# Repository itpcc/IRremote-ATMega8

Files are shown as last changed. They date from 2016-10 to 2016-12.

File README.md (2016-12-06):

# IRremote-ATMega8

This project is for creating a device to control electronic device with infrared controlled by Smartphone or anything which can connected by Wi-Fi via ESP8266 (However, we communicate with ESP8266 via Serial due to subject restriction policy).

This project is created by:

- [Mr. Pongpon Kampan](https://github.com/owlaaz)
- [Mr. Rachasak Ragkamnerd](https://github.com/itpcc)

This project is a project of CPE363 Embedded device from [CPE KMUTT](https://cpe.kmutt.ac.th).

## Schematic

[Eagle file](Schematic/schematic.sch)

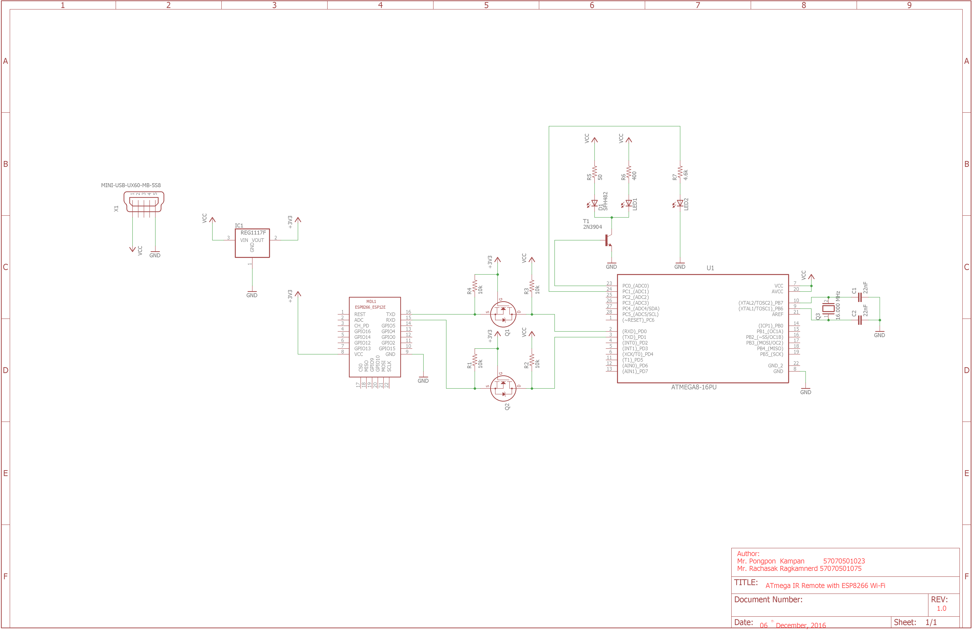
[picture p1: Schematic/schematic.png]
Eagle file


## Read more

- [Custom protocol (applied from NMEA protocol) used in this project (in Thai)](ir_protocol.md)
- [Example Android application used for project demo](https://github.com/owlaaz/IRRemote-Mobile-To-ESP8266)
- [Project Report](Project Report.pdf)

## Applied repository
- [Arduino IR Remote](https://github.com/z3t0/Arduino-IRremote)
- [Daikin IR Remote](https://github.com/mharizanov/Daikin-AC-remote-control-over-the-Internet)

## Resource 

- [IR Database](http://irdb.tk/api)
- [Using AVR UART](http://www.appelsiini.net/2011/simple-usart-with-avr-libc)
- [Logic level converter](https://learn.sparkfun.com/tutorials/bi-directional-logic-level-converter-hookup-guide)
- [Schematic for LIRC](http://alexba.in/blog/2013/03/09/raspberrypi-ir-schematic-for-lirc/)
- [AVR fus bit calculator](https://elektronik-kompendium.de/public/arnerossius/programme/web/avrfuse/m8fuse.html)
- [USBasp](http://eecs.oregonstate.edu/education/docs/ece375/USBASP-UG.pdf#page=8)

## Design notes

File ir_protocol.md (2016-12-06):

Protocol

Reference: [NMEA Protocol](https://en.wikipedia.org/wiki/NMEA_0183)

# รับ IP ที่จะให้ติดต่อ (UDP)

```
$IRCIP,192.168.1.112*47
        |----------|
          Phone IP
```

# ขอคำสั่ง (ESP-TCP)
```
$IRREQ,00000*41
         |
         --- IR Sent command ID (00000 if no command sent) คำสั่งล่าสุดที่ทำไปแล้ว
```

# ส่งคำสั่ง (จากเครื่องควบคุม) (Mobile-TCP)
```
$IRCMD,1,00FAF,RC5,48260482,12*73
       |   |    |      |     |
       |   |    |      |     --- nbits (ถ้ามีระบุใน IR Command) หรือ address กรณี panasonic
       |   |    |      --- Command HEX code 
       |   |    --- protocol (3 char)
       |   --- Command unique ID (5 alphanumeric)
       --- Remaining command count (1 ยังเหลือ 0 หมดแล้ว)
$IRCMD,0,00001,NEC,A1DE21DE,32*46
```

## Protocol
- RC5
- RC6
- PAN (Panasonic)
- NEC
- SAM (Samsung)

# ไม่มีข้อมูลให้ทำ :v

```
$IREMP*44
```

# Invalid received command
```
$IRIVD*40
```

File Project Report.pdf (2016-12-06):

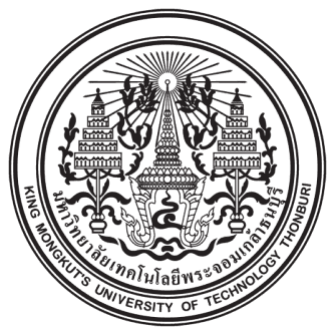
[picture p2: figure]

# Final Project Universal IR Remote

นายราชศักดิ์ รักษ์ก าเนิด | 57070501075
นายปองพล | ค าปัน | 57070501023

# วิชา Embedded Systems Design CPE 363 ภาควิชาวิศวกรรมคอมพิวเตอร์

# มหาวิทยาลัยเทคโนโลยีพระจอมเกล้าธนบุรี

ก

ชื่อโครงงาน | : | Universal IR Remote
ชื่อผู้จัดท าโครงงาน | : | นายปองพล | ค าปัน
นายราชศักดิ์ รักษ์ก าเนิด
อาจารย์ที่ปรึกษา | : | นายไกรกร | เศรษฐไกรกุล
| | นายธกรตั้งมั่นคง
คณะวิศวกรรมศาสตร์
ภาควิชาวิศวกรรมคอมพิวเตอร์
มหาวิทยาลัยมหาวิทยาลัยเทคโนโลยีพระจอมเกล้าธนบุรีสารบัญ
| | | บทคัดย่อ

ปัจจุบันทุกๆบ้านล้วนแต่มีเครื่องใช้ไฟฟ้า ที่คอยอ านวยความสะดวกสบายให้แก่ผู้ใช้งาน โดยส่วนใหญ่ล้วนแล้วแต่ใช้รีโมท ควบคุมการท างาน โดยการที่จะสั่งการท างานจากรีโมทนั้นจะท าการส่งชุดข้อมูลที่ประกอบไปด้วยค าสั่งฐานสิบหก (hex commmand)และรูปแบบรหัส ผ่านสัญญาณอินฟราเรด รีโมททุกๆเครื่องนั้นจะมีรูปแบบสัญญาณอินฟราเรดที่ส่งออกนั้น ต่างกัน ท าให้เกิดค าสั่งควบคุมที่ต่างกัน รวมไปถึงรูปแบบของการถอดรหัสที่แต่ละผู้ผลิตเครื่องใช้ไฟฟ้ามีรูปแบบเฉพาะที่ไม่ เหมือนกัน หากเรารู้ถึงค าสั่งฐานสิบหกและรูปแบบรหัสอุปกรณ์นั้นๆ เราสามารถเลียนแบบสร้างสัญญาณอินฟราเรดเพื่อสั่งให้ อุปกรณ์เหล่านั้นท างานได้Universal IR Remote จะเป็นอุปกรณ์ที่ท าการรวบรวมค าสั่งฐานสิบหกและรูปแบบของการถอดรหัส แต่ละอุปกรณ์ไว้และท าการสร้างสัญญาณอินฟราเรดของชุดข้อมูลเหล่านั้นเพื่อควบคุมอุปกรณ์ท าให้มีสะดวกยิ่งขึ้น อีกทั้งยัง เพื่อให้ผู้ศึกษาเข้าใจถึงการท างานของส่วนต่างๆ ในวงจรทั้งการท างานของ ESP8266,ATmega8 และ LED เพื่อประโยชน์ต่อการ น าไปศึกษาต่อไปในอนาคต

ค าส าคัญ : ค าสั่งฐานสิบหก, รูปแบบของรหัส, สัญญาณอินฟราเรด,ควบคุม

ข

กิตติกรรมประกาศ
โครงงาน Universal IR Remote ได้รับความช่วยเหลืออย่างสูงจากอาจารย์ไกรกร เศรษฐไกรกุลและอาจารย์ธกร ตั้ง มั่นคงอาจารย์ที่ปรึกษาโครงงาน ที่กรุณาสละเวลาช่วยให้ค าปรึกษาแนะน า และตรวจสอบ แก้ไข ข้อพกพร่องทุกขั้นตอนของการ จัดท าโครงงาน เพื่อพัฒนาปรับปรุงโครงงานให้มีประสิทธิภาพมากขึ้น ตลอดจนคอยติดตามเอาใจใส่ความคืบหน้าของโครงงานนี้อยู่ เสมอ จึงท าให้โครงงานนี้ส าเร็จลุล่วงไปได้ด้วยดี คณะผู้จัดท าจึงขอกราบขอบพระคุณเป็นอย่างสูงมา ณ ที่นี้
ขอขอบคุณเจ้าหน้าที่ Hardware House ที่สนับสนุนให้ยืมอุปกรณ์ จนโครงงานนี้สามารถส าเร็จลุล่วงไปได้ด้วยดี ขอขอบคุณอาจารย์ เพื่อนในชั้นเรียน และคณะผู้จัดท าโครงงานที่คอยเป็นก าลังใจให้ให้ความช่วยเหลือ ให้ค าปรึกษา

คณะผู้จัดท าโครงงาน

ค

สารบัญ

เรื่อง | หน้า
บทคัดย่อ | ก
กิตติกรรมประกาศ | ข
สารบัญ | ค-ง
บทที่ 1 บทน า | 1
1.1 ความเป็นมาและความส าคัญของโครงงาน | 1
1.2 วัตถุประสงศ์ของโครงงาน | 1
1.3 ขอบเขตการศึกษา | 1
1.4 แผนการด าเนินงาน | 1
1.5 ผลที่คาดว่าจะได้รับ | 1
บทที่ 2 เอกสารที่เกี่ยวข้อง
2.1 อินฟราเรด | 2
2.2 AVR Microcontroller | 2
2.3 รีโมตคอนโทรล | 3
2.4 Embedded System | 3
บทที่3 การออกแบบวงจร | 4-6
3.1 อุปกรณ์ที่ใช้ | 4
3.2 Diagram การท างาน Universal IR Remote | 4
3.3 Flow Chart แสดงการท างานของ Universal IR Remote | 4-5
3.4 ค าสั่งติดต่อการท างานระหว่าง โทรศัพท์มือถือ และ ESP8266 (Request & Response) | 6
บทที่ 4 ผลการทดลอง | 7-9
4.1 Schematic Universal IR Remote | 7
4.2 ล าดับการท างาน | 7-9
บทที่ 5 อภิปรายและสรุปผลการทดลอง | 10
5.1 อภิปรายผลการทดลอง | 10
5.2 สรุปผลการทดลอง | 10
5.3 ข้อเสนอแนะ | 10

ง

บรรณานุกรม | 10
ภาคผนวก | 11

บทที่ 1 บทน า

### 1.1 ที่มาและความส าคัญ

เนื่องจากในปัจจุบันการควบคุมเครื่องใช้ไฟฟ้า อุปกรณ์ภายในบ้านถูกควบคุมผ่านรีโมทคอนโทลที่มีสัญญาณอินฟราเรด เป็นตัวส่งรหัสค าสั่ง เมื่อเรามีเครื่องใช้ไฟฟ้า อุปกรณ์มากขึ้น รีโมทจะต้องมีมากขึ้นตาม คณะผู้จัดท าจึงมีแนวคิดที่ว่ารีโมทหนึ่งอัน สามารถควมคุมอุปกรณ์ได้ทุกอย่าง และรีโมทนั้นไม่จ าเป็นต้องรีโมทเสมอไป เพื่อให้สะดวกต่อการใช้งาน คณะผู้จัดท าจึงได้เลือกใช้ อุปกรณ์โทรศัพท์มือถือที่ทุกคนมีติดตัว ท าเป็นรีโมทควบคุมแทน จึงเกิดเป็น universal IR remote โดยได้น าความรู้ในวิชา CPE 363 Embedded System Design มาเป็นพื้นฐานในการท าโครงงาน

### 1.2 วัตถุประสงค์ของโครงงาน

1.เพื่อศึกษาและสร้าง IR Remote ที่สามารถควบคุมอุปกรณ์ไฟฟ้าได้หลายชนิด

### 1.3 ขอบเขตการศึกษา

สร้าง Remote ควบคุมบนโทรศัพท์มือถือ ที่ส่งชุดค าสั่งผ่าน TCP/UDP ไปยัง ESP8266 ที่เชื่อมต่อในเครือข่ายเดียวกัน และESP8266 ส่งค าสั่งการท างานไปที่ ATmega8 เพื่อให้ ir led ส่งสัญญาณอินฟราเรดตามค าสั่งที่ได้รับให้กับอุปกรณ์ไฟฟ้า

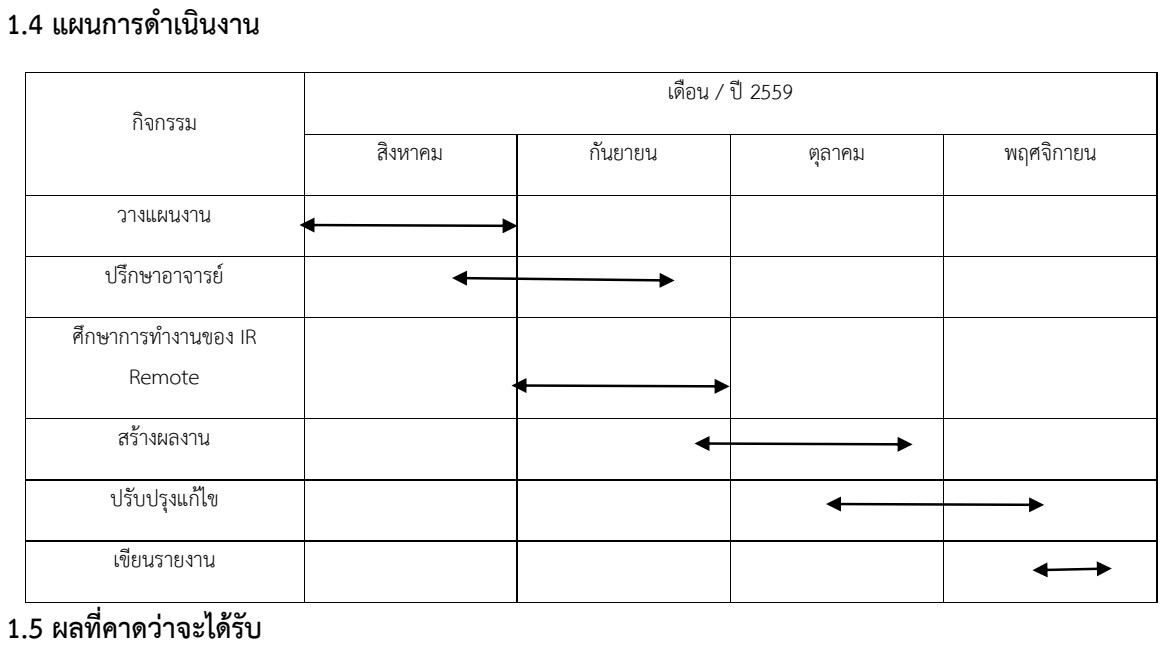
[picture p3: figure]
1.4 แผนการด าเนินงาน; กิจกรรม; สิงหาคม; กันยายน; ตุลาคม; พฤศจิกายน; วางแผนงาน; ปรึกษาอาจารย์; ศึกษาการท างานของ IR Remote; สร้างผลงาน; ปรับปรุงแก้ไข; เขียนรายงาน 1.5 ผลที่คาดว่าจะได้รับ

1. สร้าง universal IR remote ที่ใช้งานได้จริง
2. ความรู้จากการใช้งาน ESP8266,ATmega8,TCP/UDP protocol น าไปต่อยอดกับงานในอนาคต

บทที่ 2 เอกสารและโครงงานที่เกี่ยวข้อง

### 2.1 อินฟราเรด

รังสีอินฟราเรด (Infrared (IR)) มีชื่อเรียกอีกชื่อว่า รังสีใต้แดง หรือรังสีความร้อน เป็นคลื่นแม่เหล็กไฟฟ้าที่มีความยาว คลื่นอยู่ระหว่างคลื่นวิทยุและแสงมีความถี่ในช่วง 1011 – 1014 เฮิร์ตซ์ มีความถี่ในช่วงเดียวกับไมโครเวฟ มีความยาวคลื่นอยู่ ระหว่างแสงสีแดงกับคลื่นวิทยุสสารทุกชนิดที่มีอุณหภูมิอยู่ระหว่าง -200 องศาเซลเซียสถึง 4,000 องศาเซลเซียส จะปล่อยรังสี อินฟราเรดออกมา คุณสมบัติเฉพาะตัวของรังสีอินฟราเรด เช่น ไม่เบี่ยงเบนในสนามแม่เหล็กไฟฟ้า ที่แตกต่างกันก็คือ คุณสมบัติที่ ขึ้นอยู่กับความถี่ คือยิ่งความถี่สูงมากขึ้น พลังงานก็สูงขึ้นด้วย
ในการใช้ประโยชน์ ใช้ในการควบคุมเครื่องใช้ระบบไกล (remote control) สร้างกล้องอินฟราเรดที่สามารถมองเห็นวัตถุ ในความมืดได้ เช่น อเมริกาสามารถใช้กล้องอินฟราเรดมองเห็นเวียตกงได้ตั้งแต่สมัยสงครามเวียดนาม และสัตว์หลายชนิดมีนัยน์ตา รับรู้รังสีชนิดนี้ได้ ท าให้มองเห็นหรือล่าเหยื่อได้ในเวลากลางคืน
การประยุกต์ใช้อินฟราเรดในชีวิตประจ าวัน
กล้องถ่ายรูปใช้กลางคืน และกล้องส่องทางไกลที่ใช้ในเวลากลางคืน แสดงภาพความร้อน เพิ่มความปลอดภัยเวลาขับรถ ในเวลากลางคืน
รีโมทคอนโทรลในเครื่องใช้ไฟฟ้าก็เป็นอินฟราเรดอีกชนิดหนึ่ง
การไล่ล่าทางทหาร มิดไซ ที่ใช้ไล่ล่าเครื่องบินก็เป็นอินฟราเรดอีกชนิดหนึ่ง
เครื่องก าเนิดความร้อนทั่วไป เช่นเตาแก๊สอินฟราเรดในครัวเรือน เครื่องก าเนิดความร้อนในห้องซาวด์น่า
แผ่นกายภาพบ าบัด มีเป็นประคบร้อนอินฟราเรด ปัจจุบันเป็นวิธีการ กายภาพบ าบัดที่ปลอดภัยชนิดหนึ่ง
เช่น ความร้อนอุณหภูมิต่ ามาจากอินฟราเรด สามารถซึมเข้าลึกถึงผิวหนัง 1-1.5นิ้ว ลดอาการปวดหัวเข่า หรือท าให้แผล เรื้อรัง โลหิตหมุนเวียนดีขึ้นจึงท าให้แผลหายเร็ว
ข้อดี
สามารถเคลื่อนย้ายอุปกรณ์ได้ง่าย
ไม่ต้องติดตั้งสัญญาณ
ข้อเสีย
ต้องไม่มีสิ่งใดมากีดขวางเส้นสายตาของทั้งเครื่องรับและเครื่องส่ง
ระยะทางในการส่งข้อมูลสั้น

### 2.2 AVR Microcontroller

AVR Microcontroller คือ IC Microcontroller ของบริษัท Atmel ที่มีสถาปัตยกรรมภายในเป็นแบบ RISC (reduced instruction set computer) โดยใช้สัญญาณนาฬิกาเพียง 1 ลูกในการปฏิบัติงานใน 1 ค าสั่ง ภายใน AVRโดยจะ ประกอบด้วยหน่วยความจ าโปรแกรมภายในที่เป็นแบบแฟลช์โปรแกรมข้อมูลได้แบบ In-System programmable ซึ่งการท างาน ของ AVR เบอร์ต่างๆ จะมีความสามารถในการที่แตกต่างกัน เพื่อรองรับรูปแบบการท างานของวงจรที่หลายหลาก

### 2.3 รีโมตคอนโทรล

รีโมตคอนโทรล (remote control) คือเครื่องมืออิเล็กทรอนิกส์ชนิดหนึ่ง ใช้ส าหรับควบคุมการด าเนินการของ สิ่งประดิษฐ์หรือเครื่องจักรต่างๆ โดยเฉพาะเครื่องใช้ไฟฟ้าภายในบ้านเช่น โทรทัศน์ เครื่องเสียง เครื่องเล่นดีวีดี จากระยะไกล โดย ไม่ใช้สายไฟเป็นตัวส่งสัญญาณ แต่ใช้อินฟราเรดแทน (หรือใช้สัญญาณวิทยุแต่พบได้น้อย) ใช้พลังงานจากแบตเตอรี่ขนาดเล็กไม่กี่ ก้อนเท่านั้น มีขนาดเหมาะมือ และมีปุ่มฟังก์ชันต่างๆ อยู่ครบครัน
รีโมตคอนโทรล เป็นการเรียกย่อมาจาก รีโมตคอนโทรลเลอร์ (remote controller) อีกต่อหนึ่ง และสามารถเรียกย่อลง ได้อีกเหลือเพียง รีโมต (อ่านว่า รี-โหมด) ในภาษาไทยสามารถใช้ค าไทยแทนได้ว่า เครื่องควบคุมระยะไกล หรือ อุปกรณ์ควบคุม ระยะไกล
รีโมทคอนโทรล จะสามารถสั่งงานได้ ต้องประกอบด้วย2สิ่งนี้คือ รหัส และ ตัวส่งสัญญาณ 1.รหัส(Code) เป็นระบบ สัญญาณจะน าออกได้ต้องมีตัวคลื่นพาน าออกไป 2.ตัวส่งสัญญาณ(Carrier) ตัวรับสัญญาณ เพื่อถอดหรือรับรหัสที่ถูกส่งมาใช้ ควบคุมอุปกรณ์ต่างๆ

### 2.4 ความหมายของ Embedded System

Embedded System คือระบบการประมวลผลที่ใช้ Chip หรือ Microcontroller ออกแบบโดยเฉพาะ ซึ่งในระบบจะ มีหน่วยประมวลผลขนาดเล็กเพื่อท าหน้าที่ประมวลผลจากโปรแกรมและควบคุมอุปกรณ์ต่างๆ ระบบการประมวลผลนี้มีความ คล้ายคลึงกับระบบคอมพิวเตอร์จะจะเป็นการฝังตัวลงในอุปกรณ์อื่นๆ เพื่อท างานเฉพาะทาง

บทที่ 3 การออกแบบ Universal IR Remote

### 3.1 อุปกรณ์ที่ใช้

1.ATmega8 | 2.ESP8266 | 3.IR LED

### 3.2 Diagram การท างาน Universal IR Remote

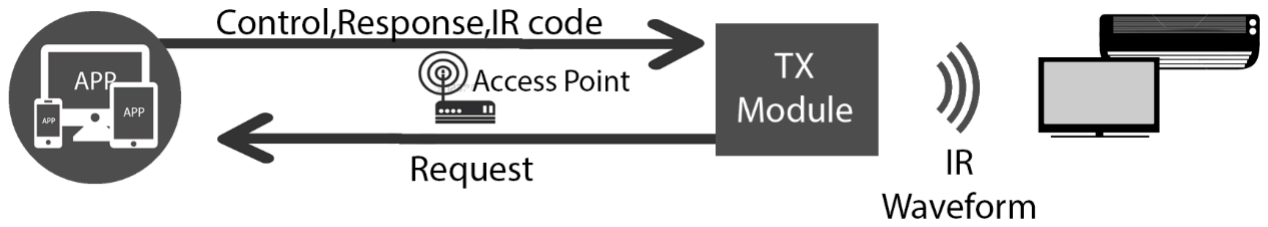
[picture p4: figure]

โทรศัพท์มือถือและ TX Module ติดต่อกันผ่าน Access Point

### 3.3 Flow Chart แสดงการท างานของ Universal IR Remote

อุปกรณ์โทรศัพท์

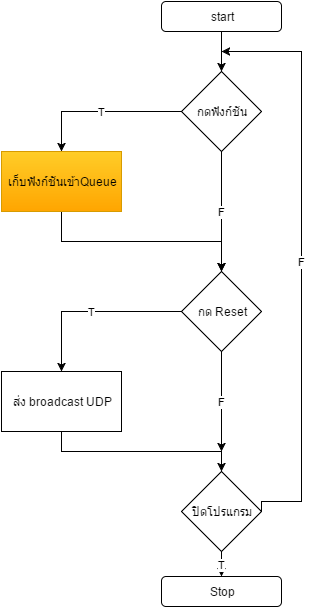
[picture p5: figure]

TX module

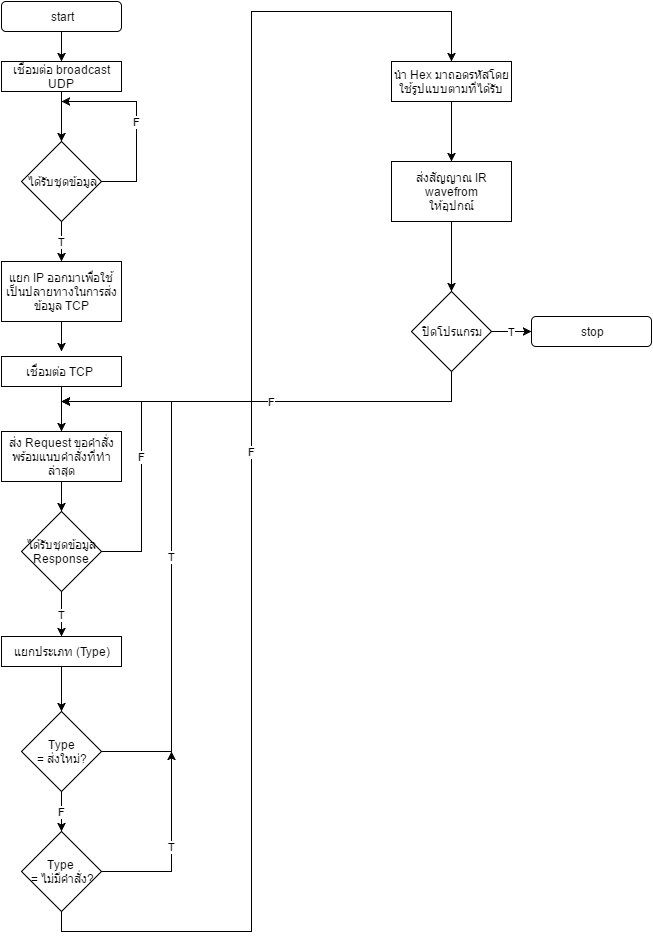
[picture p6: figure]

### 3.4 ค าสั่งติดต่อการท างานระหว่าง โทรศัพท์มือถือ และ ESP8266 (Request & Response)

รูปแบบค าสั่ง | ESP8266 | โทรศัพท์มือถือ | ตัวอย่าง | การ เชื่อมต่อ
$IRCIP,<Address>*checksum | รับ ค่า Address อุปกรณ์ควบคุม | ส่ง Address ตนเอง | $IRCIP,192.168.1.112 *47 | UDP
$IRREQ,<ค าสั่งที่ท าเสร็จ ล่าสุด>*checksum | ส่ง Request | รับ Request เตรียม ส่ง Response ค าสั่ง | $IRREQ,00000*41 | TCP
$IRCMD,<มีค าสั่งเหลือ>,<ID ค าสั่ง>, <รูปแบบรหัส>,<HEXค าสั่ง>,<nbits> *checksum | รับ ค าสั่ง | ส่ง ค าสั่ง ที่อยู่ใน Queue การท างาน | $IRCMD,1,00FAF,RC5 ,48260482,12*73 | TCP
$IREMP*checksum | รับ ค าสั่ง | ส่งค าสั่ง เมื่อไม่มีค าสั่ง เหลืออยู่ใน Queue การท างาน | $IREMP*44 | TCP
$IRIVD*checksum | ส่ง ค าสั่งเมื่อค าสั่งที่ รับล่าสุดไม่ถูกต้อง รับ ค าสั่งเพื่อส่ง ค าสั่งล่าสุด | รับ ค าสั่งเพื่อส่งค าสั่ง ล่าสุด ส่ง ค าสั่งเมื่อค าสั่งที่ รับล่าสุดไม่ถูกต้อง | $IRIVD*40 | TCP

บทที่ 4 ผลการทดลอง

### 4.1 Schematic Universal IR Remote

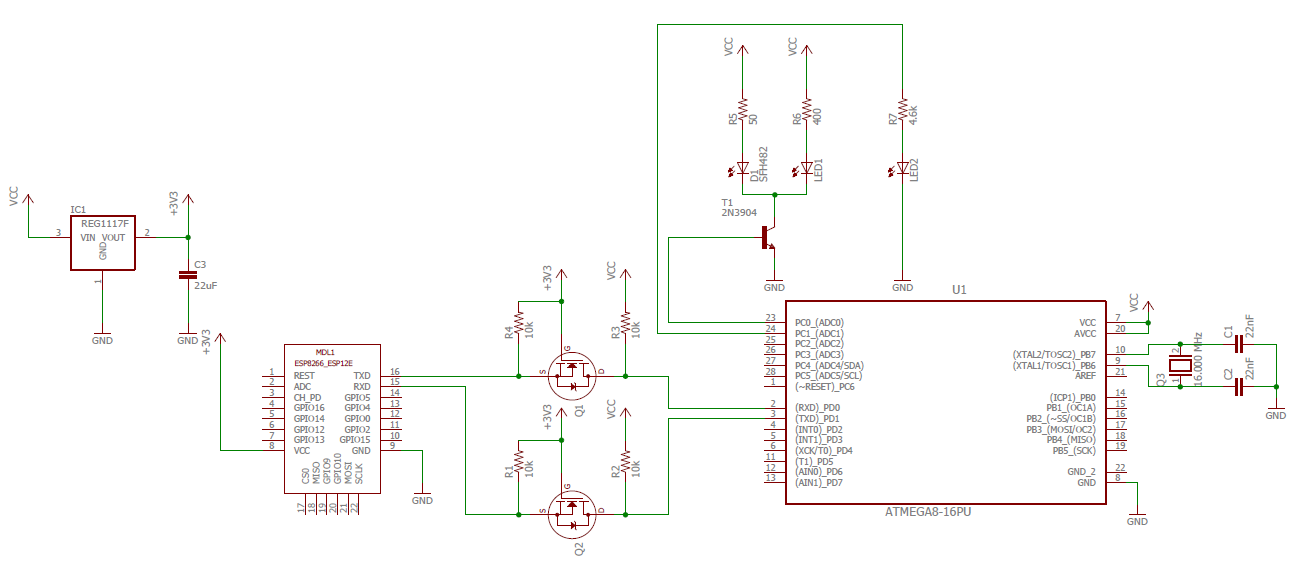
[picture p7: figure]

4.2ล าดับการท างาน

ประกอบไปด้วย TX module(ATmega8,ESP8266,IR led) โดยที่ ESP8266 จะมีหน้าที่รับชุดค าสั่งจากโทรศัพท์มือถือ ผ่าน TCP/UDP protocol เมื่อรับชุดค าสั่งแล้วจะส่งไปยัง ATmega8 เพื่อท าการแยกและแปลชุดค าสั่งให้ออกมาในรูปสัญญาณ บน IR led

1.การสั่งการบนโทรศัพท์มือถือ

ผู้ใช้งานสามารถกดฟังก์ชันรีโมทต่างๆ ได้ เมื่อกดแล้วชุดค าสั่งที่เกี่ยวข้องกับฟังก์ชันนั้นจะถูกเก็บเข้าล าดับ เพื่อเตรียม ส่งไปยังเมื่อ TX module มีการ Request ผ่าน TCP protocol

2.การเชื่อมต่อระหว่างโทรศัพท์มือถือ กับ TX module

เริ่มต้นคือการตั้งค่า ESP8266 ของ TX module ให้รับ Broadcast UDP ในเครือข่ายเดียวกัน

จากนั้นท าการส่งชุดค าสั่ง $IRCIP,<Address>*checksum จากโทรศัพท์มือถือ บน Broadcast UDP ให้ESP8266 ของ TX module

เมื่อ TX module ได้รับชุดค าสั่งจะท าการ (ประมวลผล ATmega8) แยก IP ออกมาเพื่อใช้เป็นปลายทางในการส่งข้อมูล จาก ESP8266 ของ TX module ไปยังโทรศัพท์ด้วย TCP protocol

3.การสื่อสารระหว่าง TX module กับ อุปกรณ์โทรศัพท์มือถือ

หลังจากที่เชื่อมต่อเรียบร้อยแล้ว TX module จะท าการส่ง Request $IRREQ,<ค าสั่งที่ท าเสร็จ ล่าสุด>*checksum ไปยังโทรศัพท์มือถือ จะมีการ Response กลับมา 3 กรณี

1. $IRCMD,<มีค าสั่งเหลือ>,<ID ค าสั่ง>,<รูปแบบรหัส>,<HEXค าสั่ง>,<nbits>*checksum

เมื่อมีค าสั่งอยู่ในล าดับที่ต้องท างาน

2. $IREMP*checksum เมื่อไม่มีค าสั่งอยู่ในล าดับการท างาน
3. $IRIVD*checksum เมื่อ Request ที่ได้รับมีค่า checksum ที่แนบมาไม่เท่ากับที่ค านวณได้จากชุดค าสั่ง

4.การส่งสัญญาณ IR ใน TX module

หลังจากที่ได้รับชุดข้อมูลจากอุปกรณ์โทรศัพท์มือถือ ATmega8 จะท าการแยกค าสั่งHEX,รูปแบบรหัส

โดยที่รูปแบบรหัสนั้นจะเป็นการบอกถึง รูปแบบของการเปิด/ปิดสัญญาณ,ระยะห่างเวลาระหว่างบิต,จ านวนบิต ที่ส่ง หลังจากนั้นจึงสั่ง IR led แสดงผลตามรูปแบบที่ได้

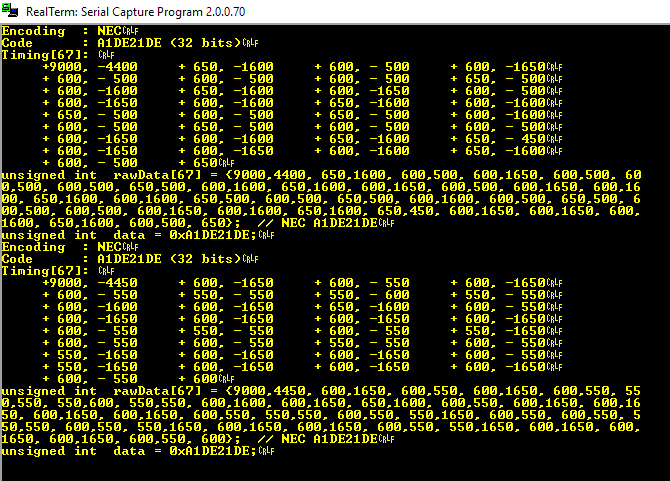
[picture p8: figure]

ชุดข้อมูลด้านบนเป็นค่าจาก TX module ของ Universal IR Remote,ชุดข้อมูลด้านบนเป็นค่าจาก Remote จริง

บทที่ 5 สรุปผล และข้อเสนอแนะ

### 5.1 อภิปรายผลการทดลอง

ในการรับส่งข้อมูลระหว่าง TX module กับโทรศัพท์มีเพียงบางช่วงที่ขาดหายไม่สามารถรับส่งข้อมูลได้

เมื่ออ่านค่าสัญญาณ IR wavefrom บน IR receiver พบว่าค่าที่ได้จากรีโมทจริงกับค่าที่ได้จาก Universal IR Remote มีค่าเหมือนกัน

### 5.2 สรุปผลการทดลอง

จากผลการทดลองพบว่า Universal IR Remote สามารถสร้างสัญญาณได้เช่นเดียวกับรีโมททั่วไป แต่เนื่องจาก หน่วยความจ าที่จ ากัดของ ATmega8 ท าให้ 1 TX module สร้างสัญญาณ IR wavefromได้เพียง 2-3 ยี่ห้อ(ตามรูปแบบรหัส) เท่านั้น

### 5.3 ข้อเสนอแนะ

ลดการโปรแกรมด้าน ESP8266 ให้น้อยลง เพิ่มจะได้มีขนาดหน่วยความจ าให้สามารถสร้าง IR wavefrom ได้มากขึ้น

บรรณานุกรม

ESP8266 กับ Arduino : เชื่อมต่อสายและอัพเดต ROM version ใหม่ (AT Command):

https://www.itpcc.net/tip-and-technic/esp8266/esp8266-w-arduino-connection-and-rom-flashing/

irdb API:

http://irdb.tk/api

ภาคผนวก

โค้ดโปรแกรมสามารถดาวน์โหลด/ดูได้ที่

https://github.com/itpcc/IRremote-ATMega8

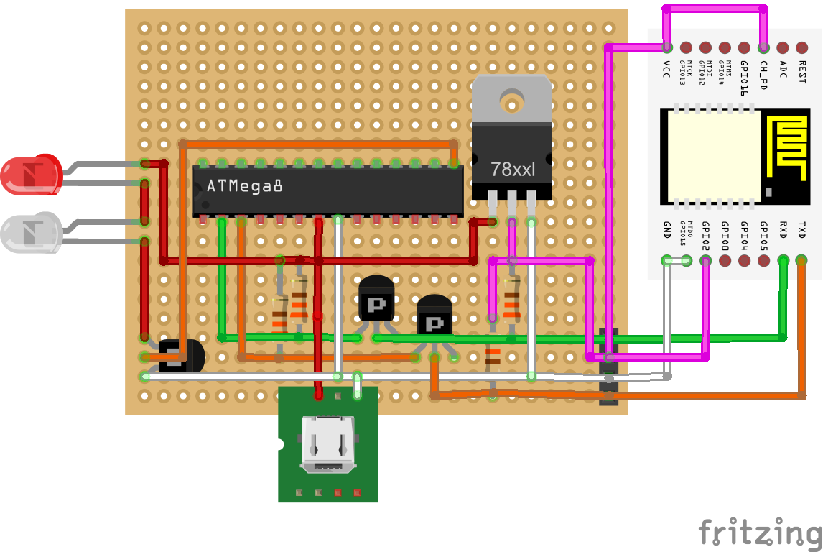
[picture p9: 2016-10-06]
perfboard_bb.png

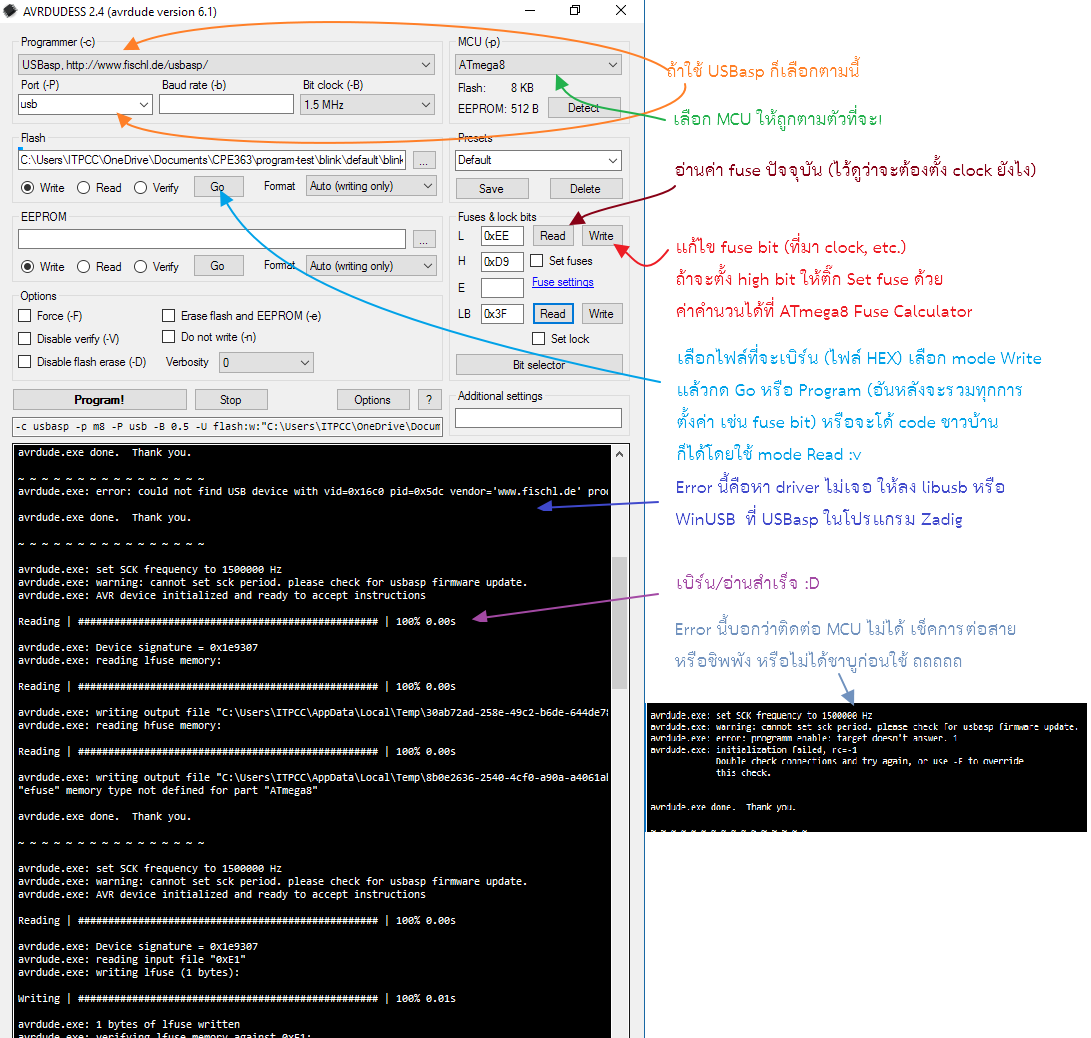
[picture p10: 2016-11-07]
Suppliment/how2avrdude.png

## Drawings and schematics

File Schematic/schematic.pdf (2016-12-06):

A

A

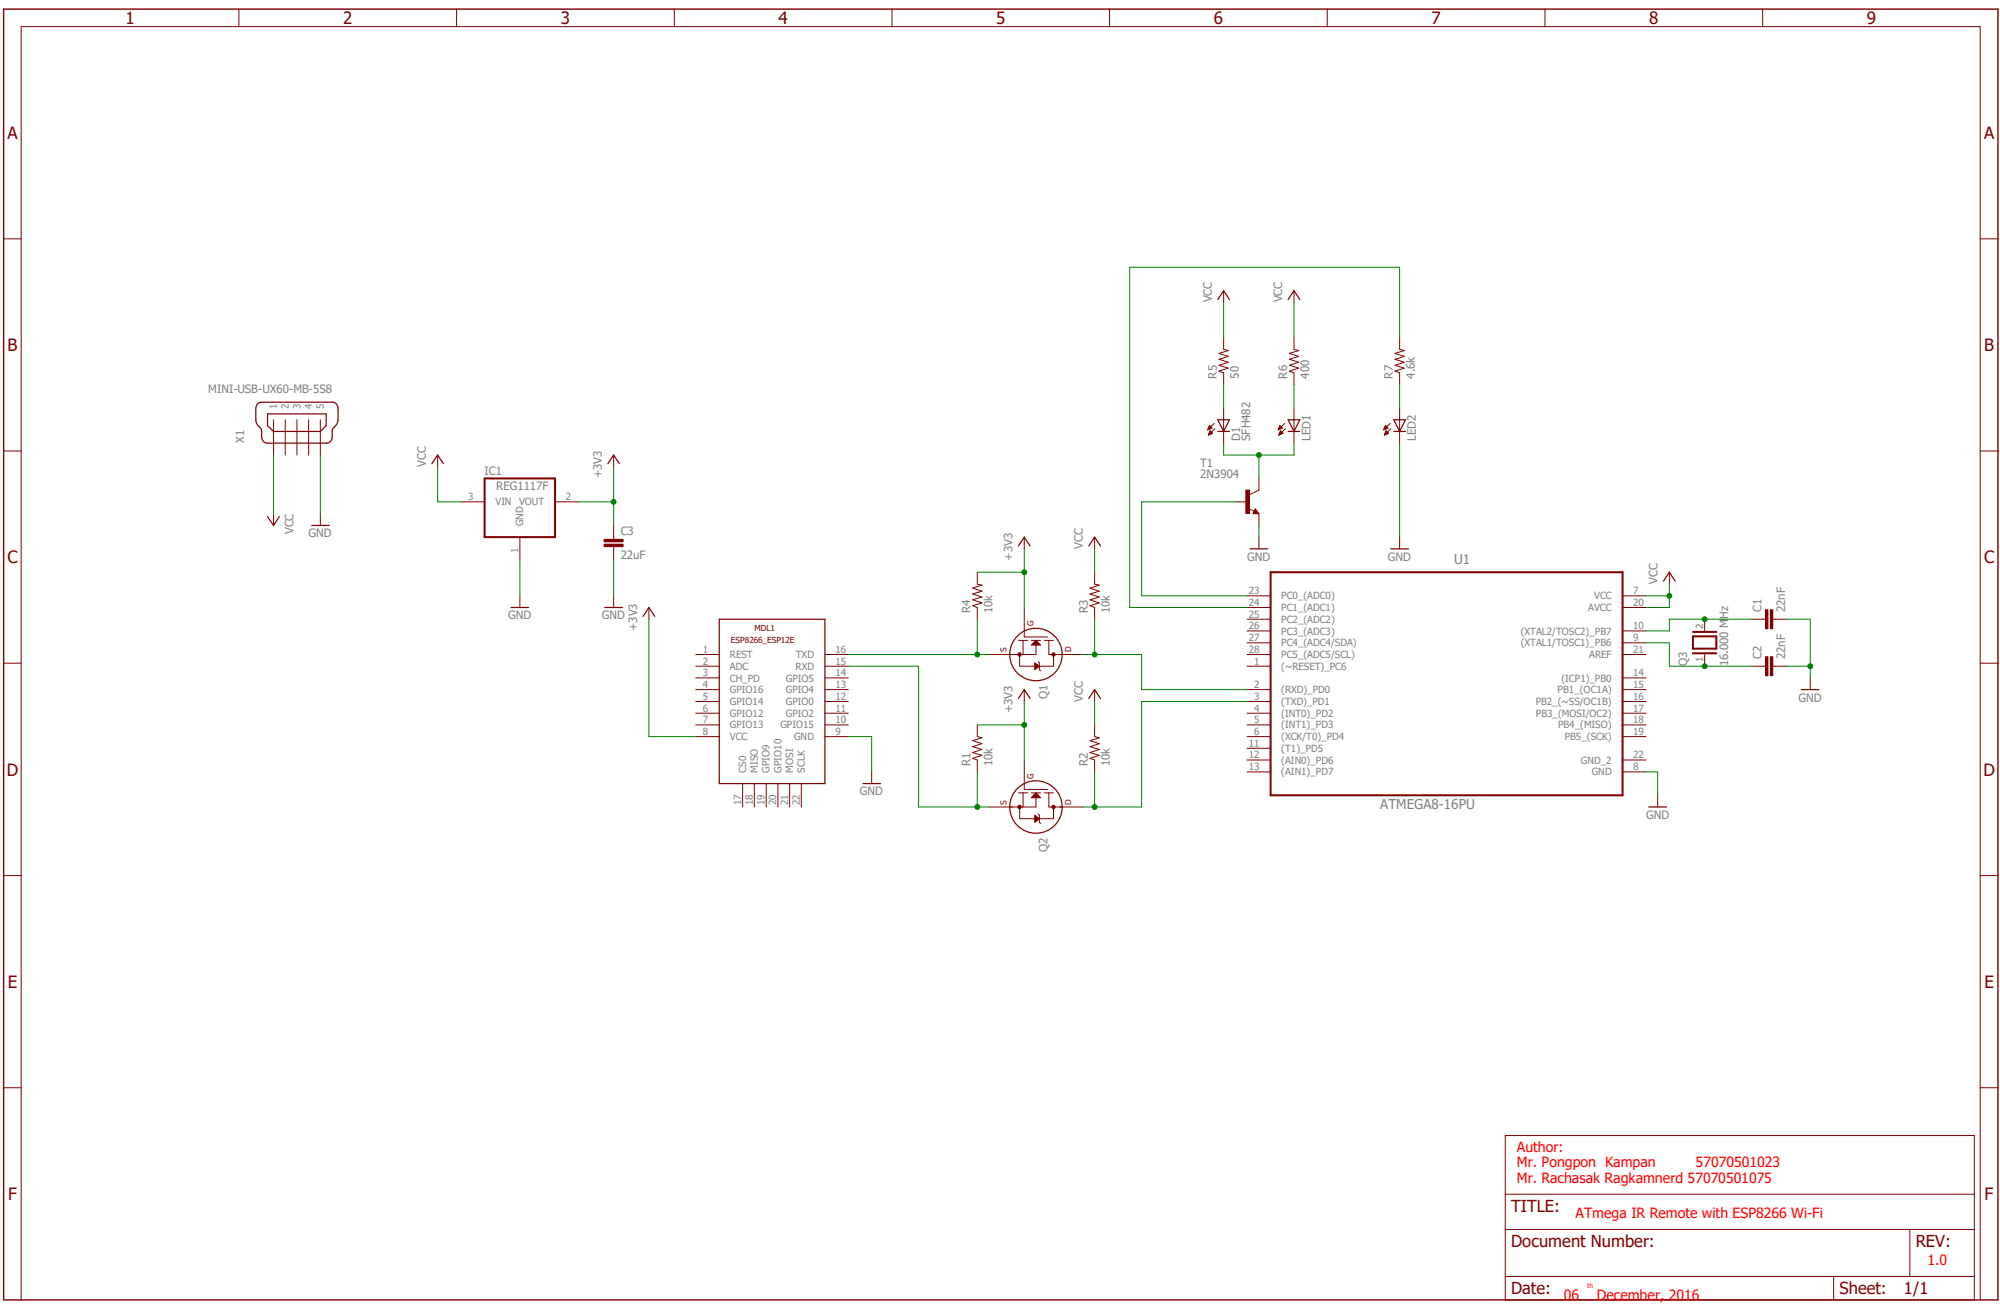
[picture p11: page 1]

ATmega IR Remote with ESP8266 Wi-Fi

Document Number: | REV: 1.0

Date: 06 December, 2016 th | Sheet: 1/1

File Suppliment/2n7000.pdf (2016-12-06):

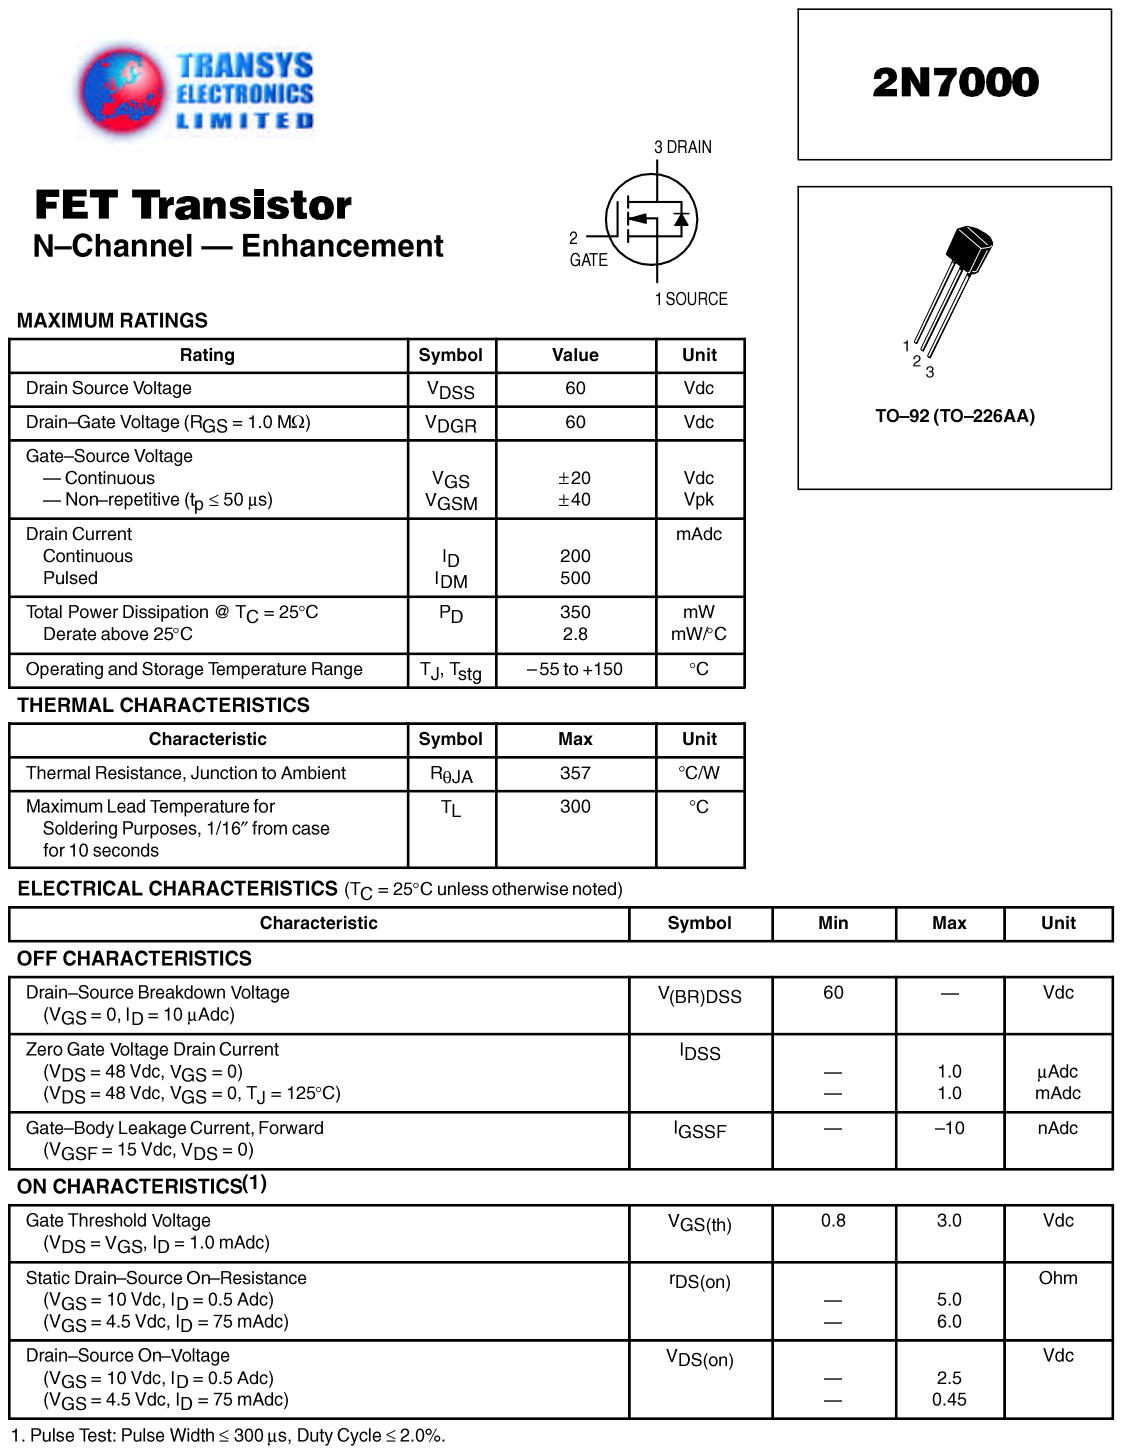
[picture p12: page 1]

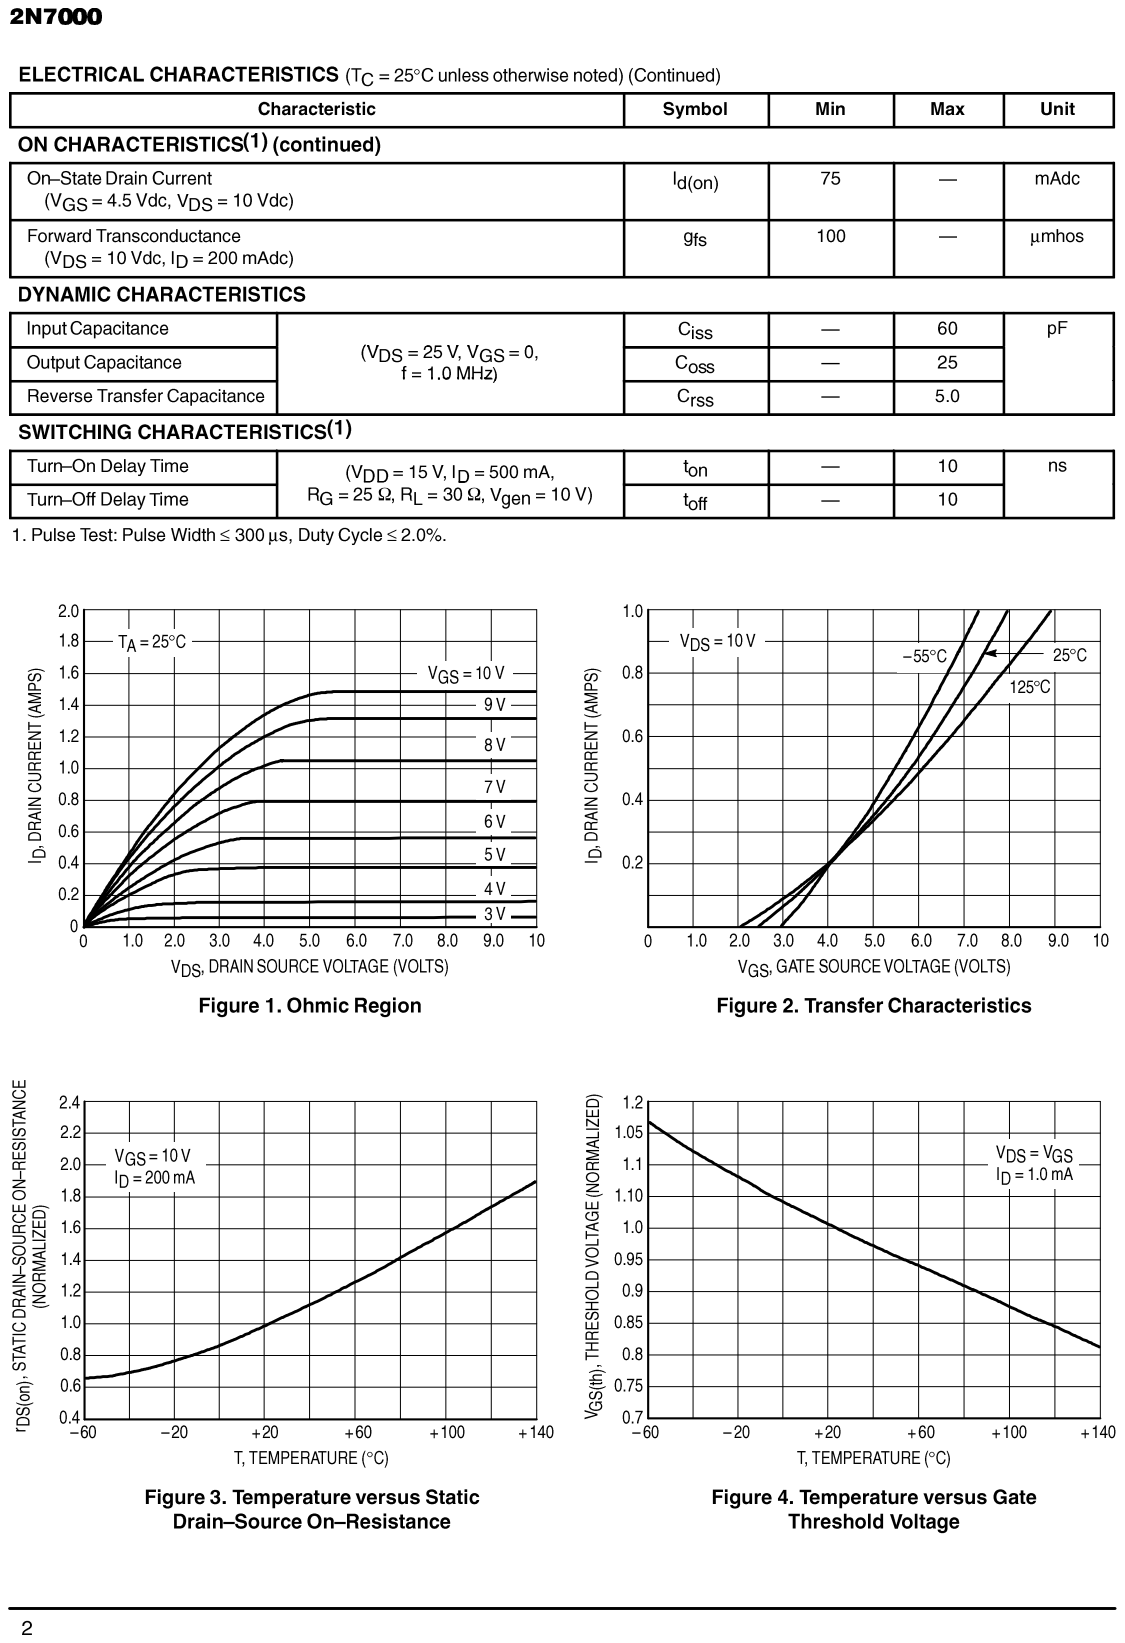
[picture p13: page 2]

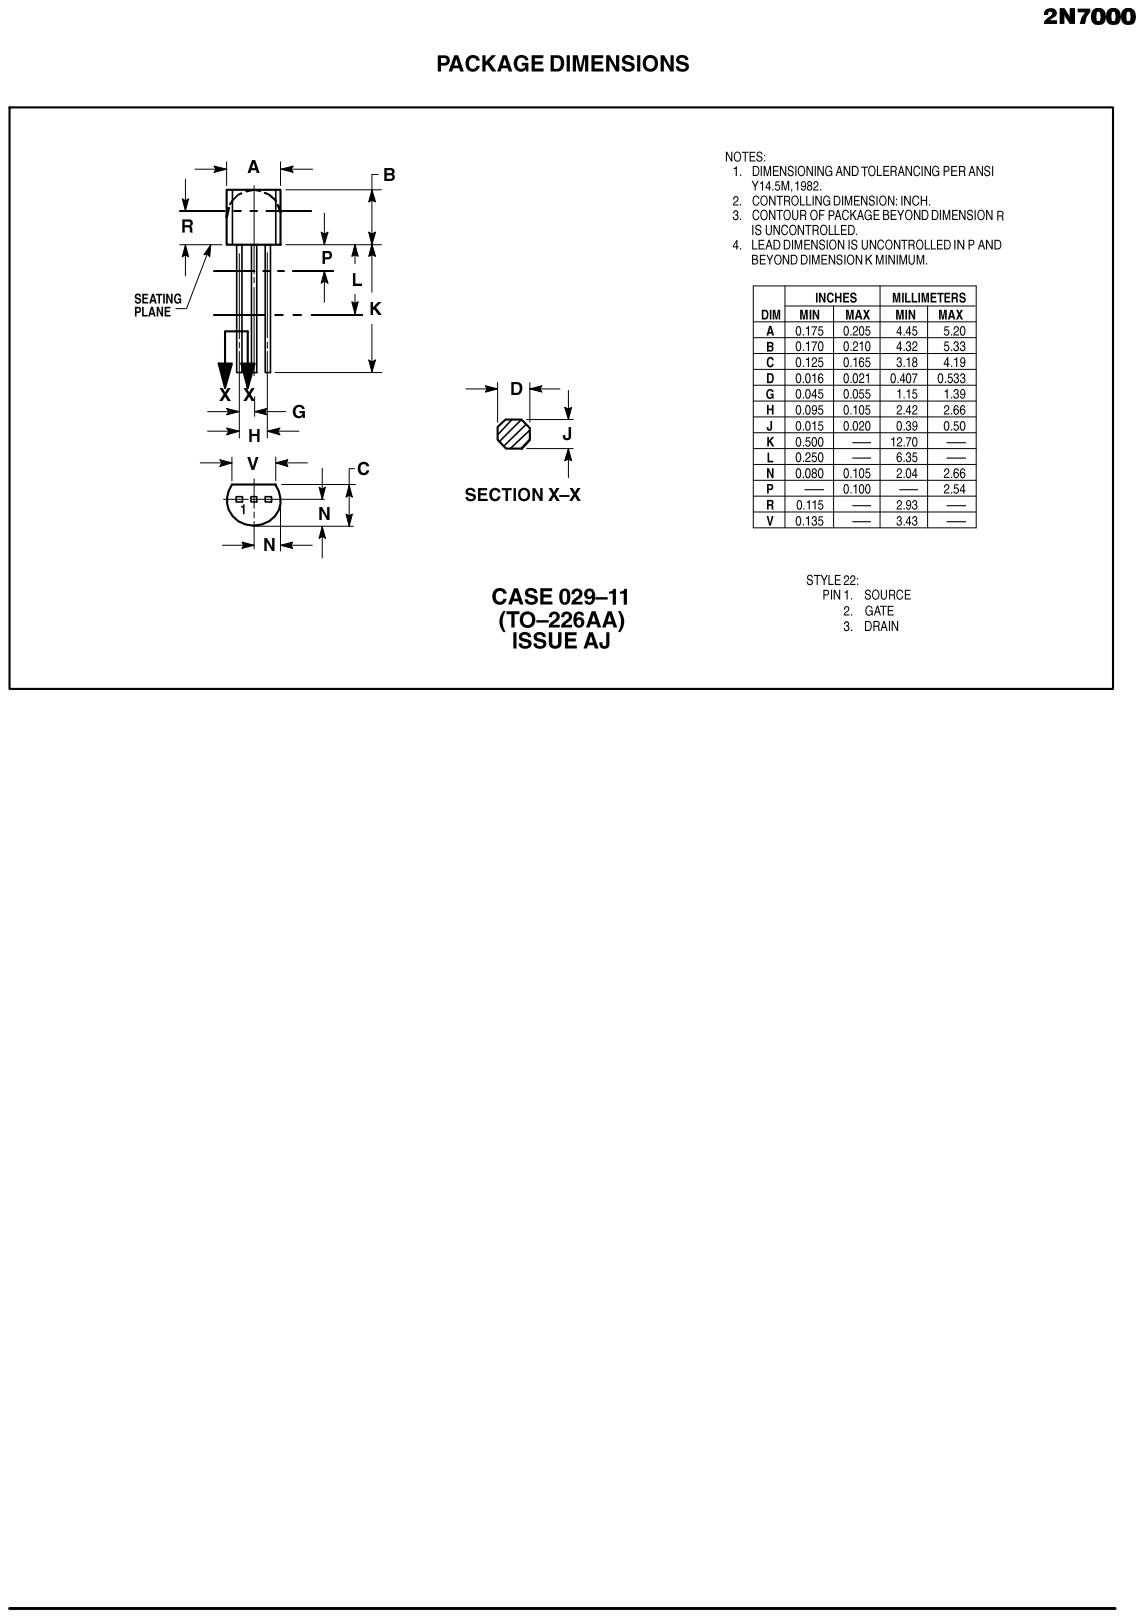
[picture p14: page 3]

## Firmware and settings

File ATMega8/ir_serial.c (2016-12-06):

#define F_CPU 16000000UL
#include <avr/io.h>
#include <avr/interrupt.h>
#include <util/atomic.h>
#include <string.h>
#include <stdlib.h>
#include "uart.h"
#include "ir_send.h"

#define ESP_DEBUG 0

#define true  1
#define false 0

#define SERIAL_RESULT_BUFFER_SIZE 101

#define ESP_STATE_INIT 0
#define ESP_STATE_SETMODE 1
#define ESP_STATE_CONNECT 2
#define ESP_STATE_CONNECT_RESPONSE 3
#define ESP_STATE_CONNECT_MUX 4
#define ESP_STATE_CONNECT_CLOSE_EXIST_CONNECTION 5
#define ESP_SET_UDP_SERVER 6
#define ESP_STATE_WAITIP 7
#define ESP_STATE_TCPCONNECT 8
#define ESP_STATE_SUCCESS 255

#define TCP_RETRY 30

/*#define WIFI_SSID "aisfibre_2.4G_F57D50"
#define WIFI_PASSWORD "6FF57D50"
#define WIFI_SSID "MNI_PROJECT"
#define WIFI_PASSWORD "irproject"*/
#define WIFI_SSID "MNI_PROJECT"
#define WIFI_PASSWORD "irproject"


volatile uint8_t ESP_CURRENT_STATE = 0;
uint8_t ESP_WIFI_CONNECTED = false;
char serialResult[SERIAL_RESULT_BUFFER_SIZE];
char *commandName, *commandDetail;
char tcpIP[16];
unsigned long IRCommand; 
int nbits;

typedef unsigned long millis_t;
volatile millis_t _milliseconds, _targetSecond;

ISR(INT0_vect){
	if(ESP_CURRENT_STATE > ESP_SET_UDP_SERVER){
		ESP_CURRENT_STATE = ESP_SET_UDP_SERVER;
	}
}

ISR(TIMER0_OVF_vect){	
	++_milliseconds;
	TCNT0 = 0x06;
	TCCR0 = _BV(CS01) | _BV(CS00); // Prescaler: 64
}

void millis_Init(void){
	_milliseconds = 0;
	TCCR0 = _BV(CS01) | _BV(CS00); // Prescaler: 64
	TCNT0 = 0x06; // 256 - 6 = 250
	TIMSK |= _BV(TOIE0);
	sei(); //enable global interrupt
}

millis_t millisec(){
	/*millis_t currMillis;
	ATOMIC_BLOCK(ATOMIC_FORCEON){
		currMillis = _milliseconds;
	}*/
	return _milliseconds;
}

void interruptDelaySetup(int second){
	_targetSecond = millisec() + (second * 1000);
}

#define interruptDelayUnFinish() (_targetSecond > millisec())

void delayMilliseconds(int ms){
	millis_t targetMS = millisec() + ms;
	while(millisec() < targetMS);
}

#if ESP_DEBUG
void Report_millisec(){
	char currMillis[16];
	UART_puts("-->"); UART_puts(ultoa(_milliseconds, currMillis, 10)); UART_putc(';');
}
#endif

uint8_t receiveSerial(){
	memset(serialResult, 0, SERIAL_RESULT_BUFFER_SIZE-1);
	#if ESP_DEBUG
		Report_millisec(); UART_puts(" WAIT INCOMING <--\r\n");
	#endif

	interruptDelaySetup(4);
	while(UART_rbuflen() == 0 && interruptDelayUnFinish());
	if(   UART_rbuflen() > 0 ){
		UART_gets(serialResult, SERIAL_RESULT_BUFFER_SIZE-1);
		if(strlen(serialResult)){ //sometime it return empty string :/
			#if ESP_DEBUG
				Report_millisec(); UART_puts("RECEIVE:"); UART_puts(serialResult);UART_puts("<--\r\n");
			#endif

			if(strstr(serialResult, "busy p..") != NULL){
				#if ESP_DEBUG
					Report_millisec(); UART_puts(" BUSY <--\r\n");
				#endif
				delayMilliseconds(500);
				return receiveSerial();
			}else if(strstr(serialResult, "WIFI DISCONNECT")){
				#if ESP_DEBUG
					Report_millisec(); UART_puts(" WIFI State change:"); UART_puts(serialResult); UART_puts("<--\r\n");
				#endif
				return receiveSerial();
			}else if(strstr(serialResult, "WIFI GOT IP")){
				#if ESP_DEBUG
					Report_millisec(); UART_puts(" WIFI State change:"); UART_puts(serialResult); UART_puts("<--\r\n");
				#endif
				if(ESP_CURRENT_STATE <= ESP_STATE_CONNECT_RESPONSE){
					ESP_CURRENT_STATE = ESP_STATE_CONNECT_MUX;
					ESP_WIFI_CONNECTED = true;
					return true;
				}
				return receiveSerial();
			}

			return true;
		}else{
			#if ESP_DEBUG
				Report_millisec(); UART_puts(" EMPTY STRING <--\r\n");
			#endif
			delayMilliseconds(100);
			return receiveSerial(); // so, we've to try again
		}
	}

	#if ESP_DEBUG
		else if(!interruptDelayUnFinish()){
			Report_millisec(); UART_puts(" Timeout <--\r\n");
		}		
	#endif

	return false;
}
uint8_t checkReturn(char *compareWord){
	
	if(receiveSerial()){
		#if ESP_DEBUG
			Report_millisec(); UART_puts("Compare:"); UART_puts(serialResult); UART_puts(" WITH:"); UART_puts(compareWord); UART_puts("<--\r\n");
		#endif

		if(strstr(serialResult, compareWord) != NULL){
			return true;
		}else{
			return false;
		}
	}else{
		#if ESP_DEBUG
			Report_millisec(); UART_puts(" Return:"); UART_puts(serialResult); UART_puts("<--\r\n");
		#endif
		return false;
	}
}

uint8_t checkUntilTimeout(char *compareWord, uint8_t maxWaitTime){
	millis_t timeoutTimestamp  = millisec() + (maxWaitTime * 1000);

	do{
		if(checkReturn(compareWord))
			return true;
	}while(millisec() < timeoutTimestamp);
	return false;
}

uint8_t sendCommand(char *sentCommand, char *compareWord){
	/*UART_putc('\r'); UART_putc('\n');*/ UART_puts(sentCommand); UART_putc('\r'); UART_putc('\n');
	if(!checkUntilTimeout(sentCommand, 1))
		return false;

	return checkUntilTimeout(compareWord, 1);
}

uint8_t nmea_get_checksum(const char *sentence){
	const char *n = sentence + 1; // Plus one, skip '$'
	uint8_t chk = 0;

	/* While current char isn't '*' or sentence ending (newline) */
	while ('*' != *n && '\r' != *n && '\n' != *n) {
		if ('\0' == *n || n - sentence > SERIAL_RESULT_BUFFER_SIZE) {
			/* Sentence too long or short */
			return 0;
		}
		chk ^= (uint8_t) *n;
		n++;
	}
	return chk;
}

uint8_t detectNMEA(){
	char *currStrPos, *dataPtr;
	uint8_t checksum, checksumResult;	

	#if ESP_DEBUG
		char numberResult[8];
	#endif

	commandName = commandDetail = NULL;
	if(!checkUntilTimeout("+IPD,", 5))	return false;

	currStrPos = strstr(serialResult, "+IPD,");
	currStrPos += 5;

	// No care String lenght
	if((currStrPos = strchr(currStrPos, '$')) == NULL)	return false;
	#if ESP_DEBUG
		Report_millisec(); UART_puts("NMEA Data:"); UART_puts(currStrPos); UART_puts("<--\r\n");
	#endif

	if((checksumResult = nmea_get_checksum(currStrPos)) == 0)	return false;
	dataPtr = currStrPos + 1;

	#if ESP_DEBUG
		Report_millisec(); UART_puts("NMEA Checksum calculate:"); UART_puts(itoa(checksumResult, numberResult, 16)); UART_puts("<--\r\n");
	#endif

	if((currStrPos = strchr(currStrPos, '*')) == NULL)	return false;
	checksum = strtol(currStrPos+1, NULL, 16);
	#if ESP_DEBUG
		Report_millisec(); UART_puts("NMEA Checksum return:"); UART_puts(itoa(checksum, numberResult, 16)); UART_puts("<--\r\n");
	#endif
	if(checksum != checksumResult) return false;

	commandName = dataPtr;
	currStrPos = strchr(dataPtr, ',');
	if(currStrPos != NULL){
		*currStrPos = '\0'; // to spilt between command name and data
		commandDetail = currStrPos+1;
		currStrPos = strchr(commandDetail, '*'); //find before checksum
	}else{
		commandDetail = NULL; // No command detail
		currStrPos = strchr(commandName, '*'); //find before checksum
	}
	
	*currStrPos = '\0'; //discard checksum

	return true;
}

char* getCurrentColumn(char *currentPoint, char **nextpoint){
	*nextpoint = strchr(currentPoint, ',');
	if(!nextpoint) *nextpoint = strchr(currentPoint, '*');
	if(nextpoint){
		**nextpoint = '\0';
		++(*nextpoint);
	}
	return currentPoint;
}

void getIRCommand(char *ptr){
	char *endptr;
	//UART_puts("-->PARSING:"); UART_puts(ptr); UART_puts("<--\r\n");
	IRCommand = strtoul(ptr, &endptr, 16);
	++endptr;
	nbits = (int)strtol(endptr, NULL, 16);
}

//for easier variable borrowing
#define statusValue retryCount
#define nmeaChecksumValue retryCount

int main(){
	uint8_t retryCount = 0;
	char commandID[8] = "00000", number[8], *tmp;

	millis_Init();
	UART_init();
	DDRB = (_BV(1) | _BV(2));
	PORTB &= ~(_BV(1) | _BV(2));
	
	PORTD = _BV(2); // INT0
	GICR |= _BV(INT0);
	MCUCR = _BV(ISC01) | _BV(ISC00);
	sei();

	/*sendNEC(0xA1DE21DE, 32);
	delayMilliseconds(500);*/
	sendNEC(strtoul("A1DE21DE", NULL, 16), 32);

	PORTB &= ~(_BV(1));

	serialResult[SERIAL_RESULT_BUFFER_SIZE-1] = '\0';
	#if ESP_DEBUG
		Report_millisec(); UART_puts("ATMega Start! <<--\r\n");
	#endif
	UART_puts("\r\nAT+RST\r\n");
	delayMilliseconds(2000);
	UART_flush();

	while(1){
		while(ESP_CURRENT_STATE < ESP_STATE_TCPCONNECT){
			if(ESP_CURRENT_STATE > ESP_STATE_INIT)
				PORTB |= _BV(2);
			delayMilliseconds(100);
			switch(ESP_CURRENT_STATE){
				case ESP_STATE_INIT:
					if(sendCommand("AT", "OK"))
						ESP_CURRENT_STATE = ESP_STATE_SETMODE;
				break;
				case ESP_STATE_SETMODE:
					if(sendCommand("AT+CWMODE=3", "OK")){
						ESP_CURRENT_STATE = ESP_STATE_CONNECT;
						UART_flush();
					}
				break;
				case ESP_STATE_CONNECT:
					UART_flush();
					UART_puts("\r\nAT+CWJAP=\""); UART_puts(WIFI_SSID); UART_puts("\",\""); UART_puts(WIFI_PASSWORD); UART_puts("\"\r\n");
					delayMilliseconds(4000);
					if(ESP_WIFI_CONNECTED == true){
						ESP_CURRENT_STATE = ESP_STATE_CONNECT;
						break;
						//UART_flush();
					}else if(ESP_CURRENT_STATE == ESP_STATE_CONNECT){
						ESP_CURRENT_STATE = ESP_STATE_CONNECT_RESPONSE;
						retryCount = 0;
						//UART_flush();
					}
				break;
				case ESP_STATE_CONNECT_RESPONSE:
					UART_flush();
					delayMilliseconds(1000);
					ESP_CURRENT_STATE = ESP_STATE_CONNECT_MUX;
					/*if(sendCommand("AT+CIPSTATUS", "STATUS:")){
						statusValue = strtol(strchr(serialResult, ':')+1, NULL, 10);
						#if ESP_DEBUG
							Report_millisec(); UART_puts("WIFI CIP Status:"); UART_putc('0'+statusValue); UART_puts("<--\r\n");
						#endif
						if(statusValue >= 2){
							ESP_CURRENT_STATE = ESP_STATE_CONNECT_MUX;
							retryCount = 0;
						}else{
							ESP_CURRENT_STATE = ESP_STATE_CONNECT;
						}
					}else if(ESP_WIFI_CONNECTED == true){
						ESP_CURRENT_STATE = ESP_STATE_CONNECT_MUX;
						break;
					}else if(strstr(serialResult, "OK")){
						retryCount = 0;
					}*/
				break;
				case ESP_STATE_CONNECT_MUX:
					UART_flush();
					if(sendCommand("AT+CIPMUX=0", "OK") || strstr(serialResult, "ERROR")){
						ESP_CURRENT_STATE = ESP_STATE_CONNECT_CLOSE_EXIST_CONNECTION;
					}
				break;
				case ESP_STATE_CONNECT_CLOSE_EXIST_CONNECTION:
					//UART_flush();
					UART_puts("AT+CIPCLOSE\r\n");
					delayMilliseconds(500);
					//sendCommand("AT+CIPCLOSE", "OK");
					//if(sendCommand("AT+CIPCLOSE", "OK") || strstr(serialResult, "ERROR") || strstr(serialResult, "FAIL")){
						ESP_CURRENT_STATE = ESP_SET_UDP_SERVER;
						retryCount = 0;
					//}
				break;
				case ESP_SET_UDP_SERVER:
					delayMilliseconds(500);
					UART_flush();
					if(sendCommand("AT+CIPSTART=\"UDP\",\"0\",0,10000,2", "CONNECT") || strstr(serialResult, "OK") || strstr(serialResult, "READY")){
						ESP_CURRENT_STATE = ESP_STATE_WAITIP;
						UART_flush();
					}else{
						++retryCount;
						#if ESP_DEBUG
							Report_millisec(); UART_puts("WIFI Connect Attemp:"); UART_putc('0'+retryCount); UART_puts("<--\r\n");
						#endif
						if(retryCount > 5)
							ESP_CURRENT_STATE = ESP_STATE_CONNECT_MUX;
					}
				break;
				case ESP_STATE_WAITIP:
					if(PORTB & _BV(2))
						PORTB &= ~_BV(2);
					else
						PORTB |=  _BV(2);

					if(detectNMEA() && commandName && commandDetail && strstr(commandName, "IRCIP")){
						#if ESP_DEBUG
							Report_millisec(); UART_puts("NMEA Name:"); UART_puts(commandName); 
							if(commandDetail){
								UART_putc(':');
								UART_puts(commandDetail);
							}
							UART_puts("<--\r\n");
						#endif
						strlcpy(tcpIP, commandDetail, 16);
						 ESP_CURRENT_STATE = ESP_STATE_TCPCONNECT;
					}
					UART_flush();
					#if ESP_DEBUG
						Report_millisec(); UART_puts("ESP Return:"); UART_puts(serialResult); UART_puts("<--\r\n");
					#endif
				break;
			}
			if(ESP_CURRENT_STATE < ESP_STATE_WAITIP)
				PORTB &= ~_BV(2);
			delayMilliseconds(100);
		}

		retryCount = 0;
		//Ready to connect TCP	
		while(retryCount <= TCP_RETRY && ESP_CURRENT_STATE > ESP_STATE_WAITIP){
			PORTB &= ~_BV(2);
			UART_puts("\r\nAT+CIPCLOSE\r\n");
			delayMilliseconds(100);
			UART_flush();
			UART_puts("\r\nAT+CIPSTART=\"TCP\",\""); UART_puts(tcpIP); UART_puts("\",10000\r\n");
			UART_flush();
			delayMilliseconds(1000);
			strcpy(serialResult, "$IRREQ,"); strcat(serialResult, commandID); strcat(serialResult, "*");
			nmeaChecksumValue = nmea_get_checksum(serialResult); strcat(serialResult, itoa(nmeaChecksumValue, number, 16));
			UART_puts("\r\nAT+CIPSEND="); UART_puts(itoa(strlen(serialResult)+1, number, 10)); UART_puts("\r\n");
			
			PORTB |= _BV(2);
			delayMilliseconds(500);
			UART_puts(serialResult);
			UART_puts("\r\n");

			strcpy(commandID, "00000");
			if(detectNMEA()){
				PORTB &= ~_BV(2);
				if(strstr(commandName, "IRCMD") != NULL){
					/*UART_puts("-->PRECUT0:"); UART_puts(commandDetail); UART_puts("<--\r\n");

					commandDetail = strchr(commandDetail, ',')+1;
					UART_puts("-->PRECUT1:"); UART_puts(getCurrentColumn(commandDetail, &tmp)); UART_puts("<--\r\n");
					commandDetail = tmp;

					strcpy(commandID, getCurrentColumn(commandDetail, &tmp)); //commandID
					commandDetail = tmp;

					UART_puts("-->PRECUT2:"); UART_puts(commandDetail); UART_puts("<--\r\n");

					commandDetail = getCurrentColumn(commandDetail, &tmp); // Protocol
					UART_puts("-->PROTOCOL:"); UART_puts(commandDetail); UART_puts("<--\r\n");*/

					// @TODO Make it real
					tmp = strtok(commandDetail, ",*"); // Remain
					//UART_puts("-->"); UART_puts(tmp); UART_puts("<--\r\n");

					strcpy(commandID, strtok(NULL, ",*"));
					tmp = strtok(NULL, ",*");
					/*UART_puts("-->PROTOCOL:"); UART_puts(tmp); UART_puts("<--\r\n");*/

					cli();
					UCSRC = 0;
					UCSR0B = 0;
					TIMSK &= ~_BV(TOIE0);
						if(strstr(tmp, "NEC") || true){
							//getIRCommand(strtok(NULL, ",*"));
							//getIRCommand("A1DE21DE,32");
							sendNEC(
								strtoul(
									strtok(NULL, ",*"
								), NULL, 16)
							,32);
							#if SEND_NEC
							// sendNEC(IRCommand, nbits);
							#endif
						}/*else if(strstr(commandDetail, "RC5")){
							getIRCommand(tmp);
							#if SEND_RC5
							sendRC5(IRCommand, nbits);
							#endif
						}else if(strstr(commandDetail, "RC6")){
							getIRCommand(tmp);
							#if SEND_RC6
							sendRC6(IRCommand, nbits);
							#endif
						}else if(strstr(commandDetail, "PAN")){
							getIRCommand(tmp);
							#if SEND_PANASONIC
							sendPanasonic((unsigned long)nbits, IRCommand);
							#endif
						}else  if(strstr(commandDetail, "SAM")){
							getIRCommand(tmp);
							#if SEND_SAMSUNG
							sendSAMSUNG((unsigned long)nbits, IRCommand);
							#endif
						}*/
					PORTB &= ~_BV(1);
					TIMSK |= _BV(TOIE0);
					UART_init();
				}
				retryCount = 0;
			}else{
				delayMilliseconds(500);
				++retryCount;
			}
		}

		ESP_CURRENT_STATE = ESP_STATE_INIT;
	}

	return 0;
}

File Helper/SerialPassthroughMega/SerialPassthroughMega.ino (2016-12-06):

/*
  SerialPassthrough sketch

  Some boards, like the Arduino 101, the MKR1000, Zero, or the Micro,
  have one hardware serial port attached to Digital pins 0-1, and a
  separate USB serial port attached to the IDE Serial Monitor.
  This means that the "serial passthrough" which is possible with
  the Arduino UNO (commonly used to interact with devices/shields that
  require configuration via serial AT commands) will not work by default.

  This sketch allows you to  emulate the serial passthrough behaviour.
  Any text you type in the IDE Serial monitor will be written
  out to the serial port on Digital pins 0 and 1, and vice-versa.

  On the 101, MKR1000, Zero, and Micro, "Serial" refers to the USB Serial port
  attached to the Serial Monitor, and "Serial1" refers to the hardware
  serial port attached to pins 0 and 1. This sketch will emulate Serial passthrough
  using those two Serial ports on the boards mentioned above,
  but you can change these names to connect any two serial ports on a board
  that has multiple ports.

   Created 23 May 2016
   by Erik Nyquist
*/

void setup() {
  Serial.begin(115200);
  Serial1.begin(115200); //ATMega
  Serial2.begin(115200); //ESP8266
}

char ch, recentCH;
char isForward = 4;
String str;

void loop() {
  if (Serial.available()) {      // If anything comes in Serial (USB),
    Serial2.write(Serial.read());   // read it and send it out Serial1 (pins 0 & 1)
  }

  if (Serial1.available()) {     // If anything comes in Serial1 (ATMega)
    ch = Serial1.read();
    if(recentCH == '\n' && ch == '-')
      isForward = 0;
    else if(isForward == 0)
      isForward = 1;
    else if(isForward == 1 && ch == '\r')
      isForward = 2;
    else if(isForward == 2 && ch == '\n')
      isForward = 3;
    else if(isForward == 3)
      isForward = 4;
    
    /*if(isForward == 0)
      Serial.print("ATMega: ");
    else */if(isForward == 4)
      Serial2.write(ch);
    
    Serial.write(ch);   // read it and send it out Serial (USB)
    recentCH = ch;
  }
  if (Serial2.available()) {     // If anything comes in Serial1 (ESP8266)
    ch = Serial2.read();
    Serial1.write(ch);   // read it and send it out Serial1 (pins 0 & 1)
    /*Serial.write(ch);
    if(ch == '\n') Serial.print("              ");*/
    /*str = Serial2.readString();
    Serial1.print(str);
    Serial.print("\r\nESP8266:");
    Serial.print(str);   // read it and send it out Serial (USB)*/
  }
}

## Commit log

2016-10-06 ADD Perfboard
    [perfboard.fzz]
2016-11-07 Add Working Daikin IR transmitter
    [perfboard.fzz]
2016-12-06 Project finished and presented! (with a great positive comment from professor)
    [Untitled Sketch.fzz, perfboard.fzz, psi_remote.xlsx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]
